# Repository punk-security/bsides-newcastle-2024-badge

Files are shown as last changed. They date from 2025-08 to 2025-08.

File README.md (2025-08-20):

# BSides Newcastle (2024) Plant badge (Little Shop of Horrors)

**This badge was given out at BSIDES Newcastle and it's a working soil sensor!**

This badge uses UV full colour silk, and we ordered them from JLCPCB using EasyEDA. The PCB was built first with AutoCAD EAGLE, then exported.

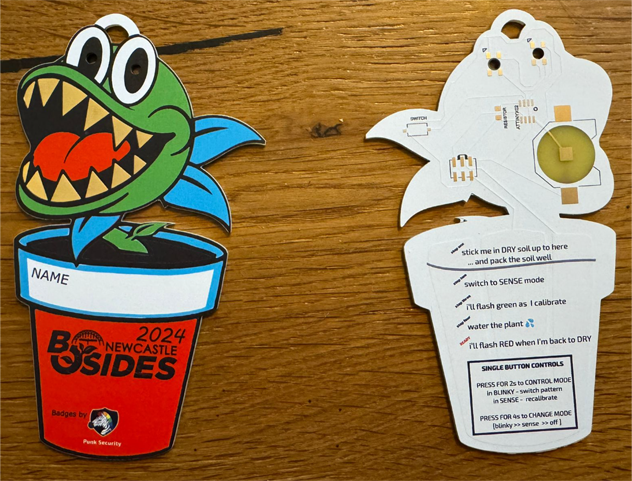
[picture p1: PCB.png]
PCB


Lots of things in this repo:

- eagle-files: all the stuff you need to tinker and modify the PCB in AutoCAD Eagle
- bsides-newcastle-2024.epro - The EasyEDA export, including the front and back art 
- gerber.zip: the file you can upload to JLCPCB and order your own badge, as is
- bsides-newcastle-2024-badge.ino: the arduino code that powers the badge, which you can modify and flash via the SAO connector

## Bill Of Materials

You can see a parts list on DigiKey [here](https://www.digikey.co.uk/en/mylists/list/1SMRGQW6IU).

Essentially its:

* ATTINY402 microcontroller
* Button - any surface mount button fitting the footprint will work
* CR2032 battery clip  - surface mount not through hole
* Neopixel 5050 addressable LED - Definitely get the right version of these
* Resistor - 6.8K 1206 resistor 

## How does it work?

The bottom of the badge (the pot) has 2 big copper pads under the artwork. Together, these act like a very tiny battery. 

This "battery" charges a little bit slower when surrounded by wet soil.

We start to charge the battery with one pin from the attiny402, and measure how charged it is with another.

This would be pretty much instant, so we slow down the charging with a resistor.

Watch my talk on the madness of developing this badge: https://www.youtube.com/watch?v=vW9SHSsYLkk

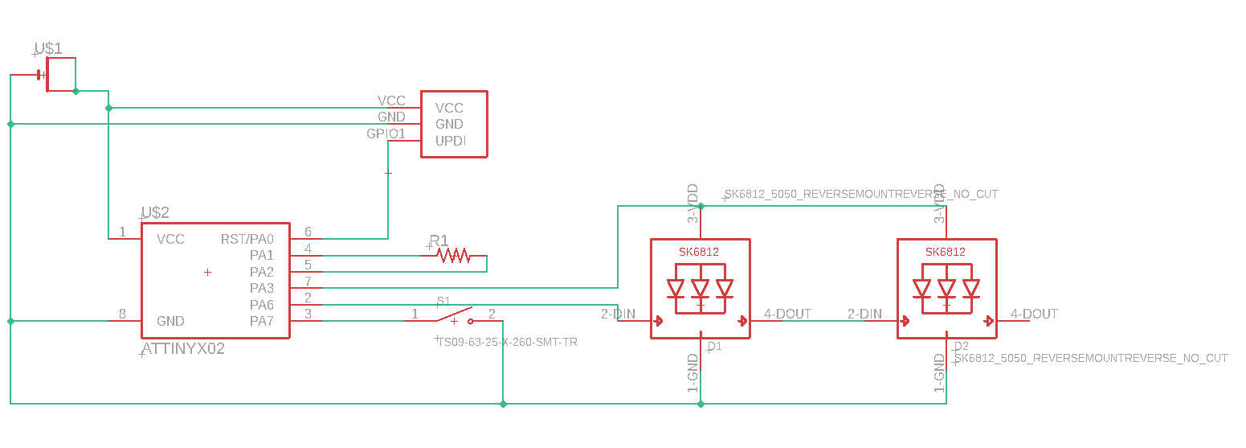
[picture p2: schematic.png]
Schematic


## Eagle designs and ordering your own badge

We've uploaded the AutoCAD EAGLE schematic and board design!  You will probably have to do some tweaks to get it working as they're not designed to be standalone exports.

This is then exported to EasyEDA to add the colour print to the boards. The file for that is already in the repo, so you can skip the EAGLE step if you prefer.

We've also uploaded the gerber.zip.  Take this to JLCPCB and you can order your own exact copies of the board :)

## Writing and flashing code!

We use [MegaTinyCore](https://github.com/SpenceKonde/megaTinyCore) for the arduino interface for ATTINY4x2 chips.

Dev and flashing is done within the Arduino IDE ( < v2 ) using a jtag2updi interface, as discussed [here](https://github.com/SpenceKonde/AVR-Guidance/blob/master/UPDI/jtag2updi.md)

We use [these little usb sticks](https://amzn.eu/d/c0lx0wG), with a 4.7k resistor soldered between the Tx and Rx lines.  

### Installing MegaTinyCore dependencies

This board package can be installed via the board manager in arduino. The boards manager URL is:

`http://drazzy.com/package_drazzy.com_index.json`

1. File -> Preferences, enter the above URL in "Additional Boards Manager URLs"
2. Tools -> Boards -> Boards Manager...
3. Wait while the list loads (takes longer than one would expect, and refreshes several times).
4. Select "megaTinyCore by Spence Konde" and click "Install". For best results, choose the most recent version.

### Setting up the IDE

1. Open the file **bsides-newcastle-2024-badge.ino** in arduino
2. Select tools > Board > megaTinyCore > ATtiny412/402/212/202
3. Select tools > Chip > ATtiny402
4. Select tools > Clock > 8Mhz internal *(we get power issues otherwise)*
5. Select tools > Programmer > SerialUPDI SLOW
6. Select tools > Port > ( pick your COM port)

### Flashing firmware
1. Connect the 3v3 pin to 3v on your usb (maybe wedge it in the battery clip)
2. Connect GND to GND
3. Connect UPDI to the RxD port
4. Click Upload button

## How to solder?

Make sure to line up the dot on the attiny402 with the dot on the board.

Make sure to line the corner of the LED with the cutout with the triangle on the board

*It's much easier if you hold the component in place with one hand, and then solder one pad. Now you can solder the rest of the pads with one hand*

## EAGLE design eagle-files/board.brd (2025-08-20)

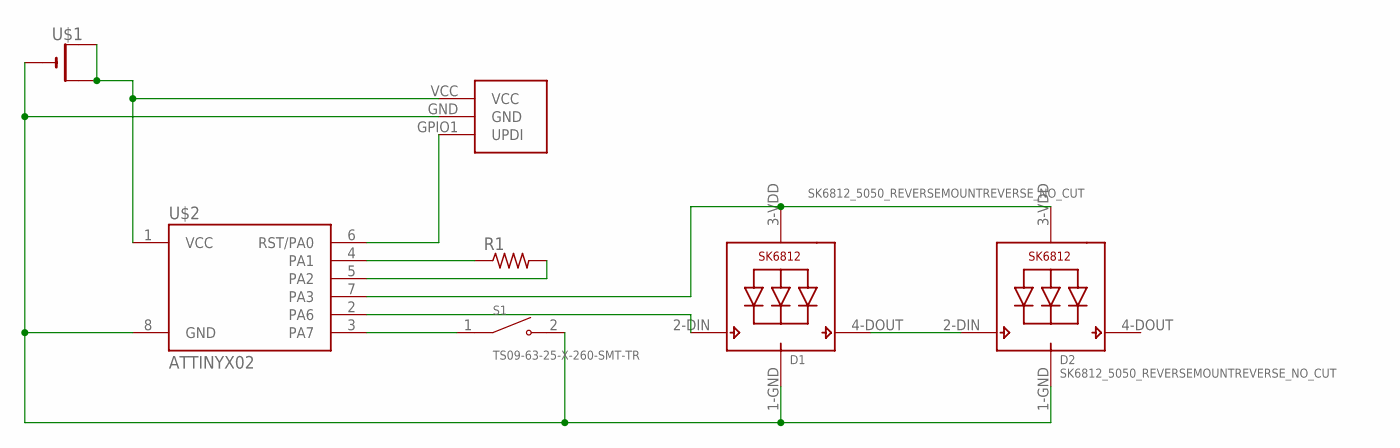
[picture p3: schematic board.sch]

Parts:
D1, D2: SK6812_5050_REVERSEMOUNTREVERSE_NO_CUT; SK6812_REVERSE_NO_CUT
R1: R-US_R1206; R1206
S1: TS09-63-25-X-260-SMT-TR; SW_TS09-63-25-X-260-SMT-TR
U$1: CR2032SMT; CR2032-SMD
U$2: ATTINYX02; SOIC08_JEDEC_150MIL
U$3: SAO; SAO_SMD

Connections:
unnamed: U$1.+$1 (+), U$1.+$2 (+1), U$2.1 (VCC), U$3.VCC
unnamed: D1.1-GND (GND), D2.1-GND (GND), S1.2, U$1.-, U$2.8 (GND), U$3.GND
unnamed: R1.1, U$2.4 (PA1)
unnamed: S1.1, U$2.3 (PA7)
unnamed: D1.2-DIN (DI), U$2.2 (PA6)
unnamed: D1.4-DOUT (DO), D2.2-DIN (DI)
unnamed: D1.3-VDD (VDD), D2.3-VDD (VDD), U$2.7 (PA3)
unnamed: U$2.6 (RST/PA0), U$3.GPIO1 (UPDI)
SENSE: R1.2, U$2.5 (PA2)

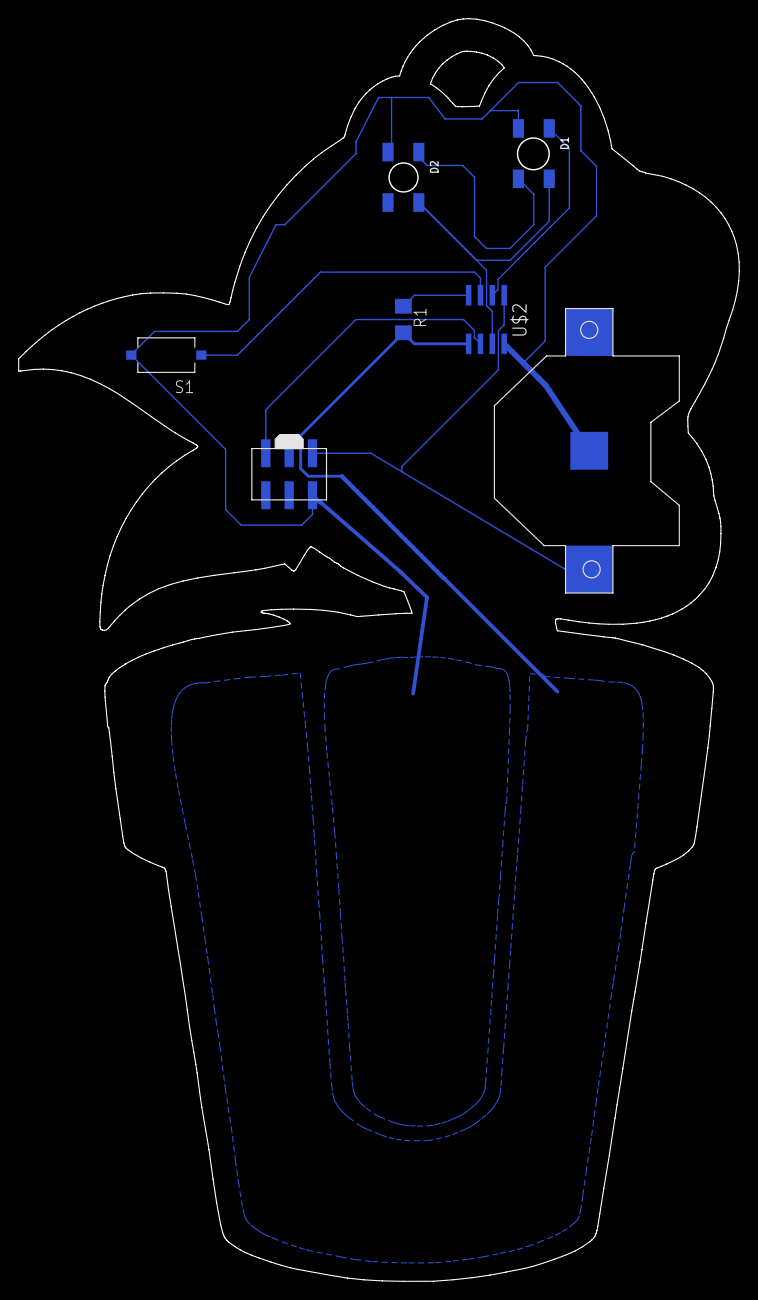
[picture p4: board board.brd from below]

Board: 2 copper layers, 77.2 x 135.3 mm, 7 parts (7 on the bottom side), 9 nets.

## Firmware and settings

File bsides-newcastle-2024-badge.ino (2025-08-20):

#include <avr/io.h>-
#include <avr/pgmspace.h>
#include <avr/sleep.h>
#include <EEPROM.h>
#include <tinyNeoPixel_Static.h>
#define NUMLEDS 2
byte pixels[NUMLEDS * 3];
tinyNeoPixel strip = tinyNeoPixel(NUMLEDS, PIN_PA6, NEO_GRB, pixels);

typedef struct AnalogReadResult {
    int16_t minValue;
    int16_t maxValue;
    int16_t delta;
};

#define BUTTON_PIN PIN_PA7

uint16_t time_pin_low(uint16_t max_ms)
{
  // blocking for up to max_ms
  if (digitalRead(BUTTON_PIN) == HIGH)
  {
    return(0);
  }
  delay(50); //debounce-
  uint16_t t = 50;
  while(digitalRead(BUTTON_PIN) == LOW)
  {
    delay(5);
    t = t + 5;
    if ( t > max_ms )
      return(max_ms);
  }
  return(t);
}

void RTC_init()
{
  /* Initialize RTC: */
  while (RTC.STATUS > 0)
  {
    ;                                   /* Wait for all register to be synchronized */
  }
  RTC.CLKSEL = RTC_CLKSEL_INT1K_gc;    /* 1kHz Internal Ultra-Low-Power Oscillator (OSCULP32K) */
}

void sleep()
{
  // Prepare for sleep and set interrupts
  set_sleep_mode(SLEEP_MODE_PWR_DOWN);
  PORTA.PIN7CTRL = PORT_PULLUPEN_bm | PORT_ISC_LEVEL_gc; // enable pullup and interrupt
  // TODO, sleep timer interrupt...
  // Turn off pins
  digitalWrite(PIN_PA3, LOW); // turn off LED power rail
  pinMode(PIN_PA2, OUTPUT);   // stop sense pin floating
  // Disable other power draining things
  ADC0.CTRLA &= ~ADC_ENABLE_bm; // disable adc
  // Enter sleep
  sleep_enable();
  sleep_cpu();
  // sleep resumes here
  // Remove interrupts
  PORTA.PIN7CTRL = PORT_PULLUPEN_bm; // renable pullup but no interrupt
  // Setup pins
  pinMode(PIN_PA2, INPUT);   // turn sense pin to input
  // Renable ADC
  ADC0.CTRLA |= ADC_ENABLE_bm; // enable ADC
}

//RTC_PERIOD_enum period = RTC_PERIOD_CYC32768_gc;
RTC_PERIOD_enum period;
void sleep_with_rtc()
{
  RTC.PITINTCTRL = RTC_PI_bm;  // Enable RTC interrupt
  RTC.PITCTRLA = period | RTC_PITEN_bm; // Set timer to 2s
  sleep();
  RTC.PITINTCTRL = ~(RTC_PI_bm); // Disable RTC interrupt
}

ISR(PORTA_PORT_vect) {
  PORTA.INTFLAGS = PORT_INT7_bm; // Clear Pin 7 interrupt flag otherwise keep coming back here
}

ISR(RTC_PIT_vect)
{
  RTC.PITINTFLAGS = RTC_PI_bm;  // Clear RTC interrupt flag otherwise keep coming back here
}



void pwm500khz() { 
  TCA0.SPLIT.CTRLD = TCA_SPLIT_SPLITM_bm;  // Enable split mode
  TCA0.SPLIT.CTRLB = TCA_SPLIT_HCMP2EN_bm; // Enable comparator in split mode
  TCA0.SPLIT.HPER = 39; // Set the period
  PORTA.DIRSET = 1 << 5; //PA5
  TCA0.SPLIT.CTRLA =
    TCA_SPLIT_CLKSEL_DIV1_gc | // divide sys. clock by 1
    TCA_SPLIT_ENABLE_bm;
   TCA0.SPLIT.HCMP2 = 20; // W05 / PA5
}

void setup()
{
  // Setup pins
  pinMode(PIN_PA1, OUTPUT);       // PWM
  pinMode(PIN_PA2, INPUT);        // SENSE
  pinMode(PIN_PA3, OUTPUT);       // LED PWR
  pinMode(PIN_PA6, OUTPUT);       // LED DATA
  pinMode(PIN_PA7, INPUT_PULLUP); // BUTTON
  // Set analog sample furation
  analogSampleDuration(1);
  // Enable serial
  //Serial.begin(9600, (SERIAL_8N1 | SERIAL_TX_ONLY));
  uint8_t ctrla = (TCA0.SINGLE.CTRLA &~(TCA_SINGLE_CLKSEL_gm)); // mask off old value
  ctrla |= TCA_SINGLE_CLKSEL_DIV1_gc; //set bits of new value // 80Khz signal
  TCA0.SINGLE.CTRLA = ctrla;  
  delay(500);
  RTC_init();
}

AnalogReadResult sense()
{
    AnalogReadResult result;
    analogRead(PIN_PA2); // Take and throw away a reading
    analogWrite(PIN_PA1, 128); // Enable PWM with 50% duty cycle
    delayMicroseconds(200); // Wait 10ms
    result.maxValue = 0;
    result.minValue = 1024;
    int16_t value = 0;
    for (int i = 0; i < 200; i++) {
      value = analogRead(PIN_PA2);
      if (value > result.maxValue) { result.maxValue = value; } // Update maxValue
      if (value < result.minValue) { result.minValue = value; } // Update minValue
    }
    digitalWrite(PIN_PA1, LOW); // Disable PWM
    result.delta = result.maxValue - result.minValue;
    return result;
}


AnalogReadResult sense2() // This takes about 3ms to read
{
    analogWrite(PIN_PA1, 128); // Enable PWM with 50% duty cycle
    ADC0.MUXPOS=0x02; //reads from PA6/arduino pin 2, ADC0 channel 6
    ADC0.CTRLA=ADC_ENABLE_bm|ADC_FREERUN_bm; //start in freerun 
    ADC0.COMMAND=ADC_STCONV_bm; //start first conversion!
    AnalogReadResult result;
    delayMicroseconds(500); // Wait 0.5ms
    result.maxValue = 0;
    result.minValue = 1024;
    int value = 0;
    for (int i = 0; i < 1000; i++) {
      value = ADC0.RES;
      if (value > result.maxValue) { result.maxValue = value; } // Update maxValue
      if (value < result.minValue) { result.minValue = value; } // Update minValue
    }
    digitalWrite(PIN_PA1, LOW); // Disable PWM
    ADC0.CTRLA = ~ADC_ENABLE_bm; // Disable ADC
    result.delta = result.maxValue - result.minValue;
    return result;    
}                                                                                                                                                                                                                                                                                                                                                                                                                                                                                                                                                                                                                                                                                                                

uint16_t calibration = 0;
uint8_t calibrate = 0;

void calibrate_sense()
{
  // This function takes an average of the current calibration value and a new reading. 
  // To calibrate from scratch, set calibrate to 0 first.
  AnalogReadResult result = sense2();
  if (calibrate == 0)
  {
    calibration = result.delta - 30; // Nothing to average, so take current minus a little bit so we alert immediately on calibration
  }
  else
  {
    calibration = (calibration + result.delta) >> 1; // Get mean of current and this one
  }
  calibrate++;
}

#define LEFT 0
#define RIGHT 1

#define OFF 0,0,0
#define RED 10,0,0
#define GREEN 0,10,0
#define BLUE 0,0,10
#define ORANGE 10,4,0
#define PINK 6,0,4
#define PURPLE 6,0,8
#define OLIVE 2,2,0
#define YELLOW 6,6,0

void flash(int r, int g, int b, uint16_t ms = 3000, int count = 1)
{
  digitalWriteFast(PIN_PA3, HIGH);
  strip.setPixelColor(LEFT, OFF);
  strip.setPixelColor(RIGHT, OFF);
  strip.show();
  for (int j = 0; j < count; j++) 
  {
    strip.setPixelColor(LEFT, r, g, b);
    strip.setPixelColor(RIGHT, r, g, b);
    for (int i = 0; i < 10; i++) 
    {
      // We need this loop otherwise the on time to data time is too quick
      strip.show();
      delayMicroseconds(100);
    }
    delay(ms);
    strip.setPixelColor(LEFT, OFF);
    strip.setPixelColor(RIGHT, OFF);
    strip.show();
    if (count > 1)
    {
      delay(ms);
    }
  }
}

int police(int x)
{
  if( x % 2 == 0)
  {
    strip.setPixelColor(LEFT,255,0,0);
    strip.setPixelColor(RIGHT,0,0,255);
  }
  else
  {
    strip.setPixelColor(RIGHT,255,0,0);
    strip.setPixelColor(LEFT,0,0,255);
  }
  strip.show();
  return 150;
}

int evil(int x)
{
  int offset = x % 40;
  if (offset < 20)
  {
    strip.setPixelColor(LEFT,offset,0,0);
    strip.setPixelColor(RIGHT,offset,0,0);
  }
  else
  {
    strip.setPixelColor(LEFT,39 - offset,0,0);
    strip.setPixelColor(RIGHT, 39 - offset,0,0);
  }
  strip.show();
  if (offset > 37)
    return 250;
   return 20;
}



int rainbow(int x, int rtn)
{
  int offset = x % 6;
  switch(offset){
    case 0:
      strip.setPixelColor(0,RED);
      strip.setPixelColor(1,ORANGE);
      break;
    case 1:
      strip.setPixelColor(0,ORANGE);
      strip.setPixelColor(1,YELLOW);
      break;
    case 2:
      strip.setPixelColor(0,YELLOW);
      strip.setPixelColor(1,GREEN);
      break;
    case 3:
      strip.setPixelColor(0,GREEN);
      strip.setPixelColor(1,BLUE);
      break;    
    case 4:
      strip.setPixelColor(0,BLUE);
      strip.setPixelColor(1,PURPLE);
      break;
    case 5:
      strip.setPixelColor(0,PURPLE);
      strip.setPixelColor(1,RED);
      break;
  }
  strip.show();
  return rtn;
}

int random_colour(int rtn)
{
  int r = random(0,20);
  int g = random(0,20);
  int b = random(0,20);
  strip.setPixelColor(LEFT,r,g,b);
  strip.setPixelColor(RIGHT,r,g,b);
  strip.show();
  return rtn;
}

int fire(int rtn)
{
  int r = random(8,10);
  int g = random(2,5);
  strip.setPixelColor(LEFT,r,g,0);
  strip.setPixelColor(RIGHT,r,g,0);
  strip.show();
  return rtn;
}

int aurora(int n)
{
  int x = n % 20;
  int y = n % 10;
  if (x < 10)
  {
    strip.setPixelColor(LEFT,15 - y,0,5 + y);
    strip.setPixelColor(RIGHT,5 + y,0,15 - y);
  }
  else
  {
    strip.setPixelColor(RIGHT,15 - y,0,5 + y);
    strip.setPixelColor(LEFT,5 + y,0,15 - y);
  }
  strip.show();
  return 10;
}

int sos(int n)
{
  int x = n % 50;
  int y = x % 4;
  bool on = false;
  if (x < 12)
  {
    // dot dot dot
    if (y == 0)
    {
      on = true;
    }
  }
  else if (x < 24)
  {
    // dash dash dash
    if (y < 3)
    {
      on = true;
    }
  }
  else if (x < 36)
  {
    // dot dot dot
    if (y < 2)
    {
      on = true;
    }
  }
  // dot dot dot pause dash dash dash pause dot dot dot pause pause
  // on off off on off off on off off off off off
  if (on) {
  strip.setPixelColor(LEFT,255,0,0);
  strip.setPixelColor(RIGHT,255,0,0);
  }
  else {
  strip.setPixelColor(LEFT,0,0,0);
  strip.setPixelColor(RIGHT,0,0,0); 
  }
  strip.show();
  return 150;
}

int halloween(int x)
{
  if( x % 2 == 0)
  {
    strip.setPixelColor(LEFT,ORANGE);
    strip.setPixelColor(RIGHT,GREEN);
  }
  else
  {
    strip.setPixelColor(RIGHT,ORANGE);
    strip.setPixelColor(LEFT,GREEN);
  }
  strip.show();
  return 150;
}

int torch()
{
  strip.setPixelColor(LEFT,255,255,255);
  strip.setPixelColor(RIGHT,255,255,255);
  strip.show();
  return 250;
}

// BADGE MODES
#define MODE_BLINKY 1
#define MODE_SENSE 2
#define MODE_OFF 3
#define MODE_END 4

// BLINKY MODES
#define BLINKY_POLICE 1
#define BLINKY_EVIL 2
#define BLINKY_RAINBOW_FAST 3
#define BLINKY_RAINBOW_SLOW 4
#define BLINKY_RANDOM 5
#define BLINKY_FIRE 6
#define BLINKY_AURORA 7
#define BLINKY_HALLOWEEN 8
#define BLINKY_SOS 9
#define BLINKY_TORCH 10
#define BLINKY_END 11

#define CALIBRATION_COUNT 5

int mode = MODE_SENSE;
int blinky_mode = BLINKY_RAINBOW_FAST;
int interval = 0;
int i = 0;

void loop() {
  if (i > 200) { i =0; }
  period = RTC_PERIOD_CYC32768_gc; // Reset timer period to 32s
  // Check if button pressed and handle action
  uint16_t btn_depress_time = time_pin_low(1000);
  bool short_press = false;
  bool long_press = false;
  if (btn_depress_time > 300){
    if (btn_depress_time > 800) {
      mode++; // Move to next mode
      flash(BLUE,40000,3);
      calibrate = 0;
    } else {
      short_press = true; // Set short press flag
    }
  }
  switch(mode) {
    case MODE_BLINKY:
      if (short_press)
      {
        blinky_mode++;
        i = 0;
        interval = 0;
        return;
      }
      digitalWriteFast(PIN_PA3,HIGH);
      delay(1);
      if (interval != 0) 
      {
        // Blinky modes involve long sleeps, so we check / delay / decrease the counter and return to the main loop
        delay(40);
        interval--;
        return;
      }
      switch(blinky_mode)
      {
        case BLINKY_POLICE:
          interval = police(i);
          break;
        case BLINKY_EVIL:
          interval = evil(i);
          break;
        case BLINKY_RAINBOW_SLOW:
          interval = rainbow(i,200);
          break;
        case BLINKY_RAINBOW_FAST:
          interval = rainbow(i,20);
          break;
        case BLINKY_RANDOM:
          interval = random_colour(100);
          break;
        case BLINKY_FIRE:
          interval = fire(10);
          break;
        case BLINKY_AURORA:
          interval = aurora(i);
          break;
        case BLINKY_HALLOWEEN:
          interval = halloween(i);
          break;
        case BLINKY_SOS:
          interval = sos(i);
          break;
        case BLINKY_TORCH:
        interval = torch();
          break;
        case BLINKY_END:
          blinky_mode = 1;
          return;
      }
      i++;
      return;
    case MODE_SENSE:
        if (short_press || long_press) { calibrate = 0; } // On short press, or if new to this mode, start calibration cycle
        if (calibrate < CALIBRATION_COUNT) { // If we need to calibrate, do that
          calibrate_sense();
          period = RTC_PERIOD_CYC4096_gc; // Shorter sleep on the next sleep as we calibrate faster
          flash(GREEN);
        }
        else // Start measuring forever
        {
          AnalogReadResult result;
          result = sense2();
          if (result.delta > calibration ) // bigger delta means dryer
          {
          flash(RED);
          period = RTC_PERIOD_CYC4096_gc; // Shorter sleep on the next sleep as we need to alert user
          }
          else
          {
            flash(GREEN);
          }
        }
        sleep_with_rtc();
        return;
    case MODE_OFF:
      sleep();
      return;
    case MODE_END:
      mode = 1;
      return;
  }
}
